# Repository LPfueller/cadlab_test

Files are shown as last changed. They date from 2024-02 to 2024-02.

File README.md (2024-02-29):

View this project on [CADLAB.io](https://cadlab.io/project/27833). 

# Crino Board - Template (RevB.1.0)

Crino offers precise characterisations of lithium ion cells for quality control in battery manufacturing and research using the *crino instrument*. Every crino instrument consists of several *crino boards* with actuators and sensors that are connected to a central control system (currently a *Raspberry Pi*). This control system is performing all measurements and also provides a user interface to interact with the system. This repository consists of Kicad development files for the *board-template*. All *crino boards* should be derived from this template. 

## Project directory structure

- **docs**: Contains additional documentation of the project.
- **hardware**: Contains the KiCad project.
- **hardware/fab**: Contains automatically generated BOM, and gerber files.
- **simulation**: Contains LTSpice simulations related to this project.

## Local Development Experience

**Prerequisites**:

If you are new to `crino development workflow`, please visit [crino-onboarding](https://github.com/crinolab/crino-onboarding) and [crino-onboarding-ecad](https://github.com/crinolab/crino-onboarding-ecad/tree/master/ecad) first.

**How to use the Template**:

Open Kicad, create a `new Project by Template`. Navigate to the following path and select the *Board Template*. Create a new project with the selected template.

- `<your path>crino-repos/crino-board/ecad/hardware`

In order to update the schematics, the newly created project has to be linked to the template. Use [git submodules](https://git-scm.com/book/en/v2/Git-Tools-Submodules) to link this repository to your task specific crino-board.

- `git submodule add -f https://github.com/crinolab/crino-board.git ./ecad/hardware/crino-board`

If you want to update you task specific crino-board to a new template, use 

- `git submodule update --init --recursive`

Open Kicad again and switch to the schematics of your new project. A block called `mcu` should be visible. Enter the properties dialog and change the *sheet name* to the following path.

- `.\crino-board\ecad\hardware\mcu.sch`

Now the schematics are linked to the template project. Appending all the symbols may be necessary. 

**How to apply changes in the Layout**

in order to apply changes in the Layout. The [KiCad Action Plugins](https://github.com/MitjaNemec/Kicad_action_plugins) have to be installed. Follow the instructions on the website.  

**Workflow for the Plugin (Rev1)**

1. After updating the submodule open the template folder
2. Open the template-layout and select TP14 (Reference Point)
3. `Tools -> External Plugins -> Save/Restore Layout -> Save Layout`
4. Select `mcu.sch` in the window and save `mcu.pckl`
5. Close template layout without saving
6. Open `mcu.pckl` and change Row `5720` 

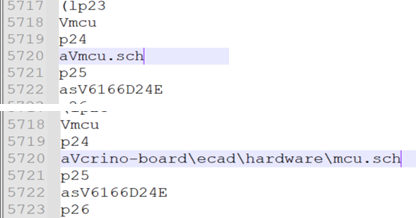
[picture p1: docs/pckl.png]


7. Open project and inspect the schematics
8. Open layout and note position of TP14
9. Delete all footprints and fracks of the template part
10. Start `Update PCB` and place the Footprints anywhere
11. Place TP14 at noted position and select it
12. `Tools -> External Plugins -> Save/Restore Layout -> Restore Layout`
13. Select `mcu.pckl` and wait until completed
14. Start DRC and correct errors
15. Save the Layout
16. Delete `mcu.pckl`

## General Components

The Template is the successor of the previously used [ESP32-POE-ISO](https://www.olimex.com/Products/IoT/ESP32/ESP32-POE-ISO/open-source-hardware). It contains all needed components of the board. 

**Basic Blocks**

The following blocks are present in the schematics:

- `poe` - Power over Ethernet controller
- `power` - Power supply for microcontroller (3.3V, 5V, 12V)
- `esp32` - [Microcontroller](https://www.espressif.com/sites/default/files/documentation/esp32-wroom-32e_esp32-wroom-32ue_datasheet_en.pdf) and programming interface  
- `ethernet` - Ethernet controller
- `io` - Pinout for derived boards

> Before you start making changes, please read the [development workflow](./docs/development-workflow.md) for Crino Power Board.

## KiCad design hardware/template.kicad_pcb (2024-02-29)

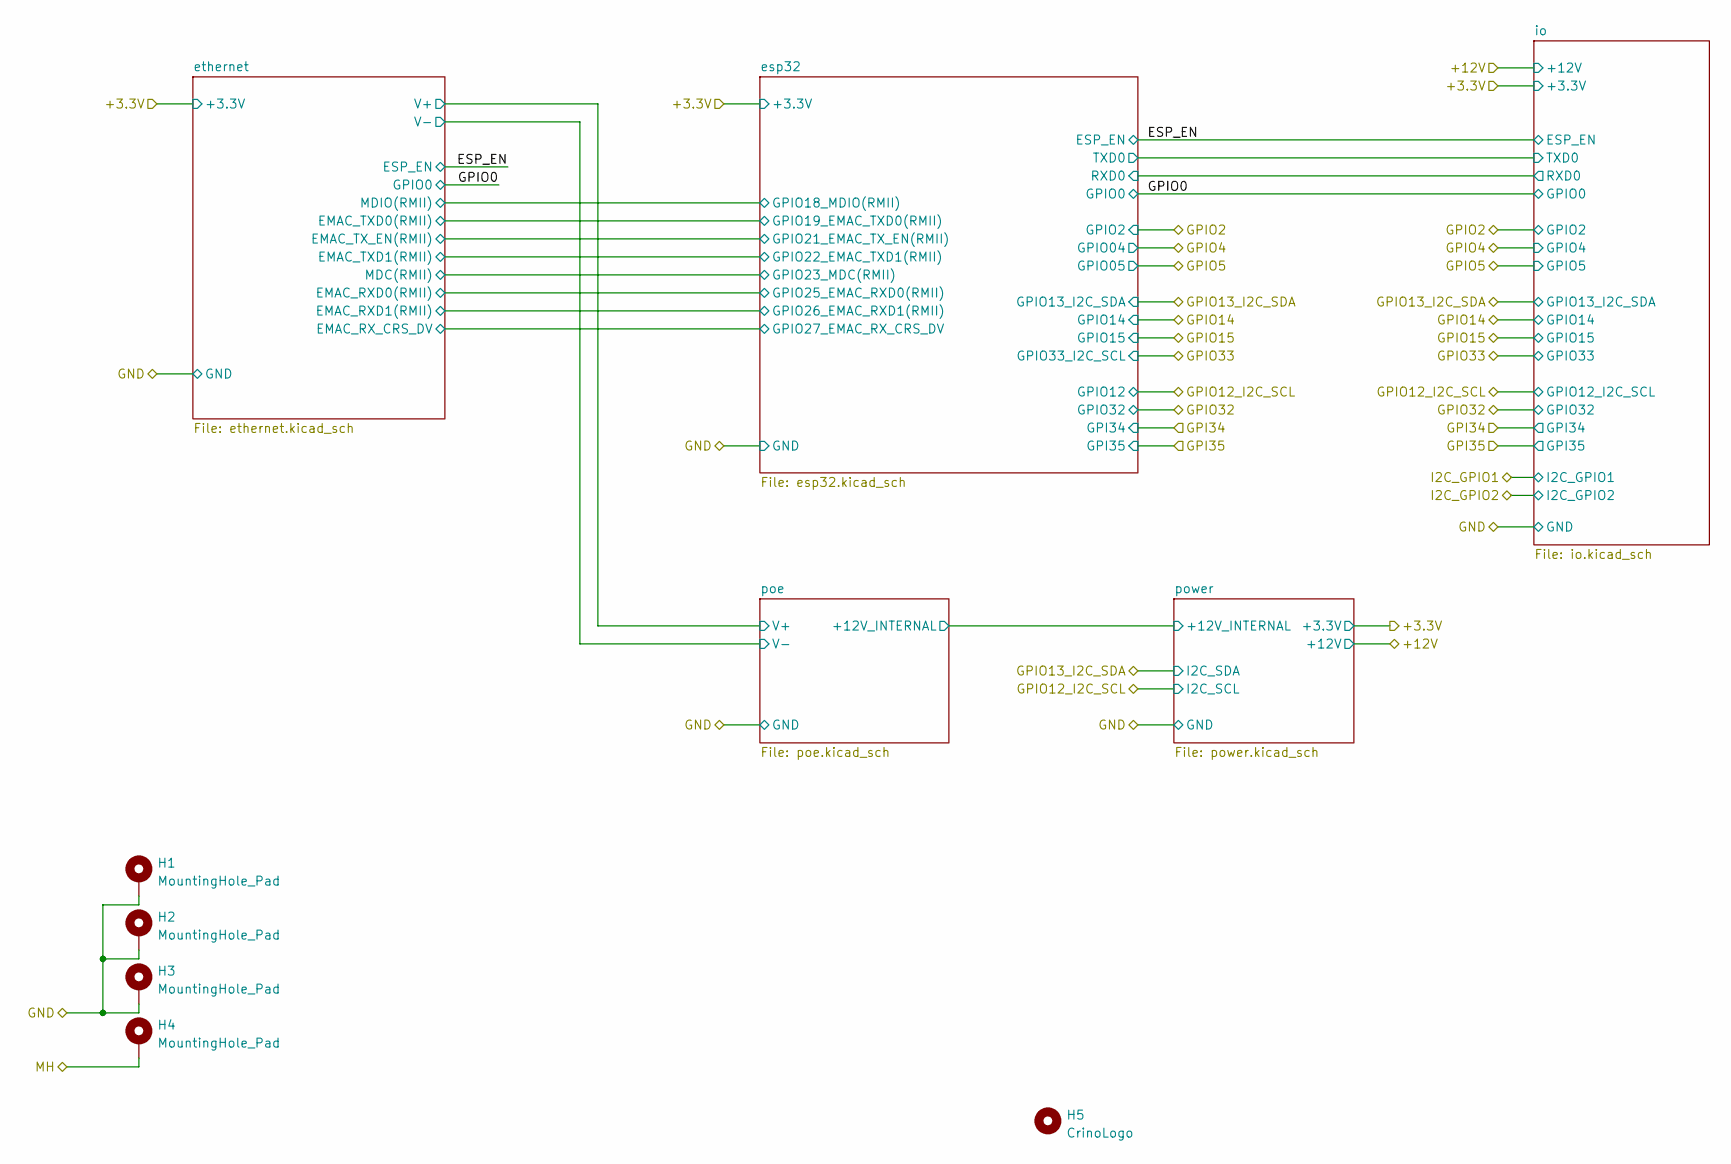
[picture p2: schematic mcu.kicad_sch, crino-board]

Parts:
H1, H2, H3, H4: MountingHole_Pad; MountingHole_3.2mm_M3_DIN965_Pad
H5: CrinoLogo; crino_logo

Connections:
/mcu/GND: H1.1, H2.1, H3.1; also elsewhere on the board
/mcu/MH: H4.1

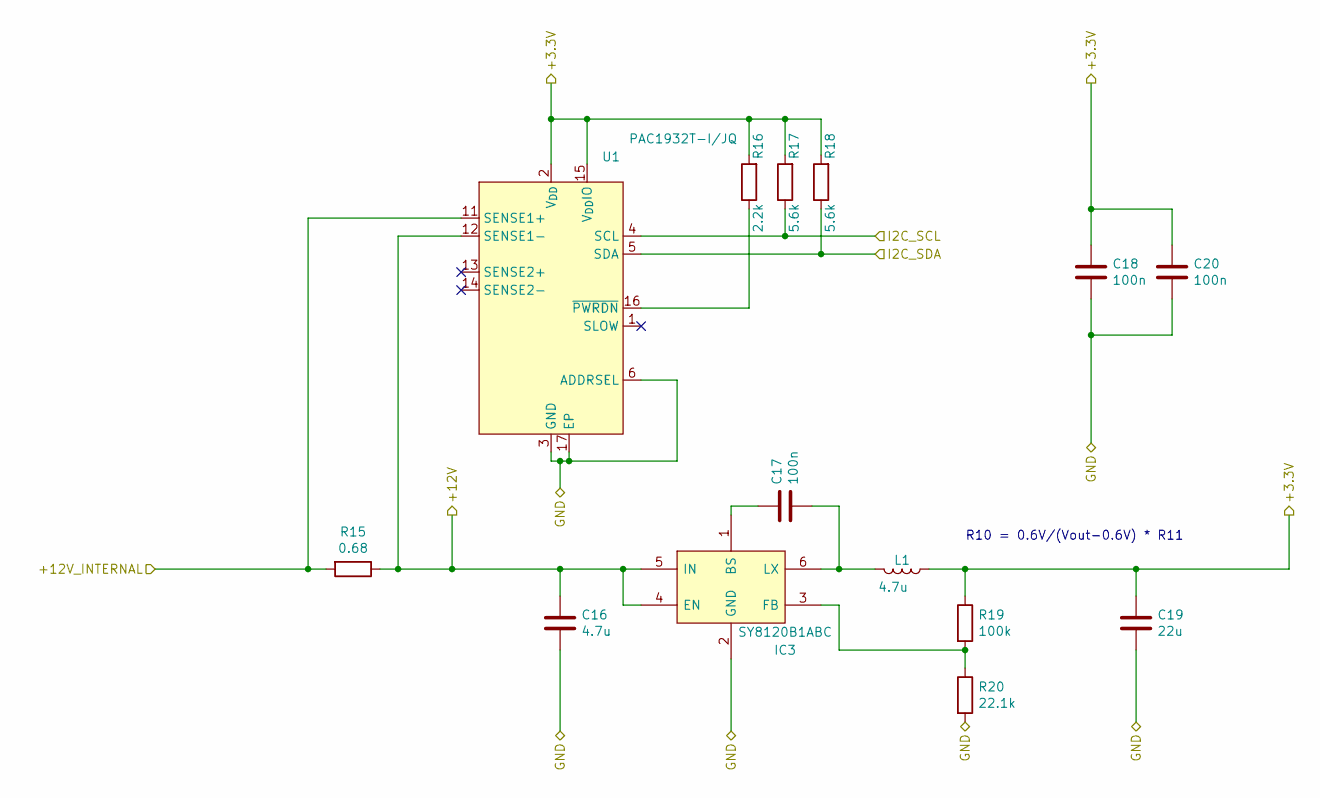
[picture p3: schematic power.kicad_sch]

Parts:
C16: 4.7u; C_0603_1608Metric; Manufacturer_Part_Number CL10A475KO8NNNC; jlc C19666
C17: 100n; C_0805_2012Metric; Manufacturer_Part_Number CL21B104KCFNNNE; jlc C28233
C18, C20: 100n; C_0603_1608Metric; Manufacturer_Part_Number CC0603KRX7R9BB104; jlc C14663
C19: 22u; C_1206_3216Metric; Manufacturer_Part_Number CL31A226KOHNNNE; jlc C90146
IC3: SY8120B1ABC; SOT-23-6; Manufacturer_Part_Number SY8120IABC; jlc C479076
L1: 4.7u; L_4.2x4.2_H2; Manufacturer_Part_Number SLW4020S4R7MST; jlc C206288
R15: 0.68; R_0805_2012Metric; Manufacturer_Part_Number SR732ATTDR680F; jlc C186593
R16: 2.2k; R_0603_1608Metric; Manufacturer_Part_Number 0603WAF2201T5E; jlc C4190
R17, R18: 5.6k; R_0603_1608Metric; Manufacturer_Part_Number 0603WAF5601T5E; jlc C23189
R19: 100k; R_0603_1608Metric; Manufacturer_Part_Number 0603WAF1003T5E; jlc C25803
R20: 22.1k; R_0603_1608Metric; Manufacturer_Part_Number 0603WAF2212T5E; jlc C25961
U1: PAC1932T-I/JQ; UQFN-16-1EP_4x4mm_P0.65mm_EP2.6x2.6mm; Manufacturer_Part_Number PAC1932T-I/JQ; jlc C623958

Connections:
/mcu/+3.3V: C18.1, C19.1, C20.1, L1.1, R16.2, R17.2, R18.2, R19.1, U1.2 (V_{DD}), U1.15 (V_{DD}IO); also elsewhere on the board
/mcu/+12V: C16.1, IC3.4 (EN), IC3.5 (IN), R15.1, U1.12 (SENSE1-); also elsewhere on the board
/mcu/GND: C16.2, C18.2, C19.2, C20.2, IC3.2 (GND), R20.2, U1.3 (GND), U1.6 (ADDRSEL), U1.7 (GND), U1.8 (GND), U1.9 (GND), U1.10 (GND), U1.17 (EP); also elsewhere on the board
/mcu/GPIO12_I2C_SCL: R17.1, U1.4 (SCL); also elsewhere on the board
/mcu/GPIO13_I2C_SDA: R18.1, U1.5 (SDA); also elsewhere on the board
/mcu/poe/+12V_INTERNAL: R15.2, U1.11 (SENSE1+); also elsewhere on the board
unnamed: C17.1, IC3.1 (BS)
unnamed: C17.2, IC3.6 (LX), L1.2
unnamed: IC3.3 (FB), R19.2, R20.1
unnamed: R16.1, U1.16 (~PWRDN)

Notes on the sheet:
R10 = 0.6V/(Vout-0.6V) * R11

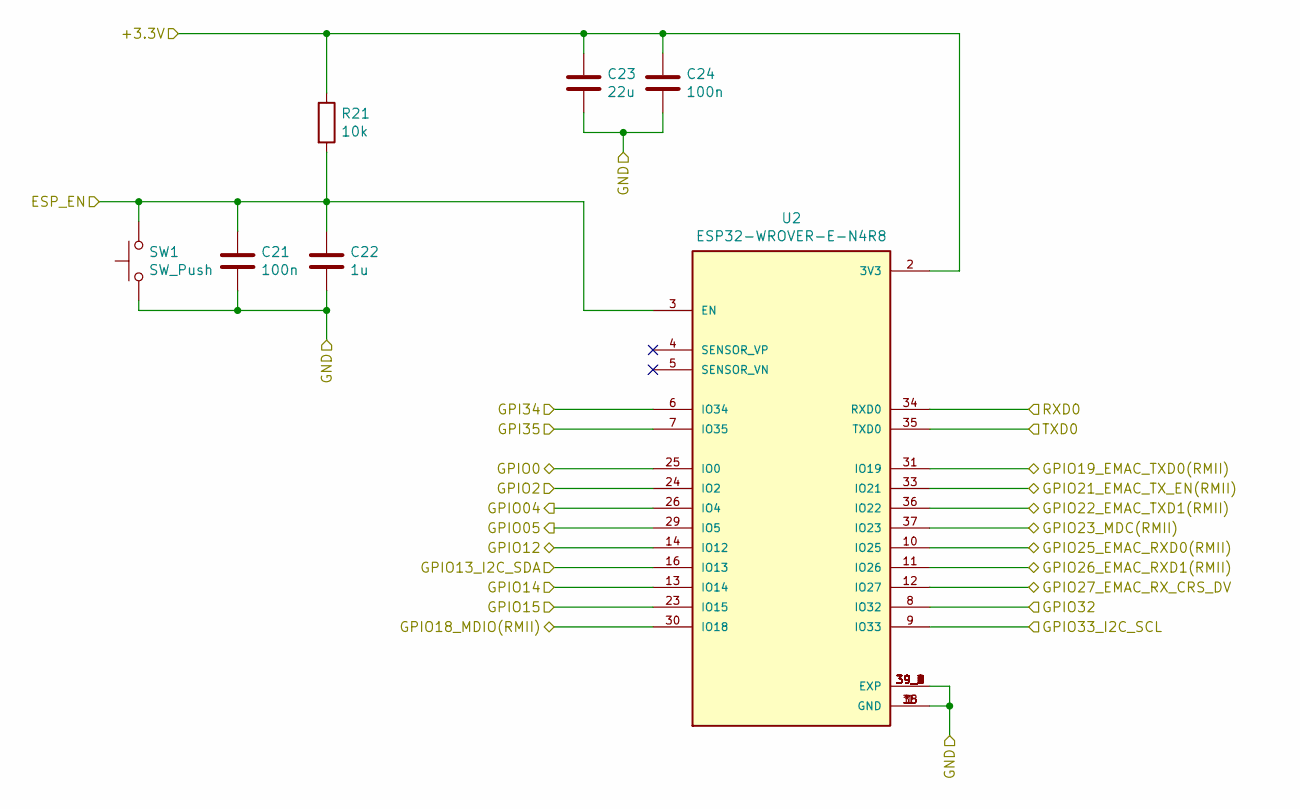
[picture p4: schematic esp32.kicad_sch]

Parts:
C21: 100n; C_0805_2012Metric; Manufacturer_Part_Number CL21B104KCFNNNE; jlc C28233
C22: 1u; C_0603_1608Metric; Manufacturer_Part_Number CL10A105KB8NNNC; jlc C15849
C23: 22u; C_0603_1608Metric; Manufacturer_Part_Number CL10A226MQ8NRNC; jlc C59461
C24: 100n; C_0603_1608Metric; Manufacturer_Part_Number CC0603KRX7R9BB104; jlc C14663
R21: 10k; R_0603_1608Metric; Manufacturer_Part_Number 0603WAF1002T5E; jlc C25804
SW1: SW_Push; SW_TS-1187A-B-A-B; Manufacturer_Part_Number TS-1187A-B-A-B; jlc C318884
U2: ESP32-WROVER-E-N4R8; PARTREV 1.6; jlc C967023

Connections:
/mcu/+3.3V: C23.1, C24.1, R21.1, U2.2 (3V3); also elsewhere on the board
/mcu/ESP_EN: C21.1, C22.1, R21.2, SW1.2, U2.3 (EN); also elsewhere on the board
/mcu/GND: C21.2, C22.2, C23.2, C24.2, SW1.1, U2.1 (GND), U2.15 (GND), U2.38 (GND), U2.39_1 (EXP), U2.39_2 (EXP), U2.39_3 (EXP), U2.39_4 (EXP), U2.39_5 (EXP), U2.39_6 (EXP), U2.39_7 (EXP), U2.39_8 (EXP), U2.39_9 (EXP); also elsewhere on the board
/mcu/GPI34: U2.6 (IO34); also elsewhere on the board
/mcu/GPI35: U2.7 (IO35); also elsewhere on the board
/mcu/GPIO0: U2.25 (IO0); also elsewhere on the board
/mcu/GPIO2: U2.24 (IO2); also elsewhere on the board
/mcu/GPIO4: U2.26 (IO4); also elsewhere on the board
/mcu/GPIO5: U2.29 (IO5); also elsewhere on the board
/mcu/GPIO12_I2C_SCL: U2.14 (IO12); also elsewhere on the board
/mcu/GPIO13_I2C_SDA: U2.16 (IO13); also elsewhere on the board
/mcu/GPIO14: U2.13 (IO14); also elsewhere on the board
/mcu/GPIO15: U2.23 (IO15); also elsewhere on the board
/mcu/GPIO32: U2.8 (IO32); also elsewhere on the board
/mcu/GPIO33: U2.9 (IO33); also elsewhere on the board
/mcu/esp32/GPIO18_MDIO(RMII): U2.30 (IO18); also elsewhere on the board
/mcu/esp32/GPIO19_EMAC_TXD0(RMII): U2.31 (IO19); also elsewhere on the board
/mcu/esp32/GPIO21_EMAC_TX_EN(RMII): U2.33 (IO21); also elsewhere on the board
/mcu/esp32/GPIO22_EMAC_TXD1(RMII): U2.36 (IO22); also elsewhere on the board
/mcu/esp32/GPIO23_MDC(RMII): U2.37 (IO23); also elsewhere on the board
/mcu/esp32/GPIO25_EMAC_RXD0(RMII): U2.10 (IO25); also elsewhere on the board
/mcu/esp32/GPIO26_EMAC_RXD1(RMII): U2.11 (IO26); also elsewhere on the board
/mcu/esp32/GPIO27_EMAC_RX_CRS_DV: U2.12 (IO27); also elsewhere on the board
/mcu/esp32/RXD0: U2.34 (RXD0); also elsewhere on the board
/mcu/esp32/TXD0: U2.35 (TXD0); also elsewhere on the board

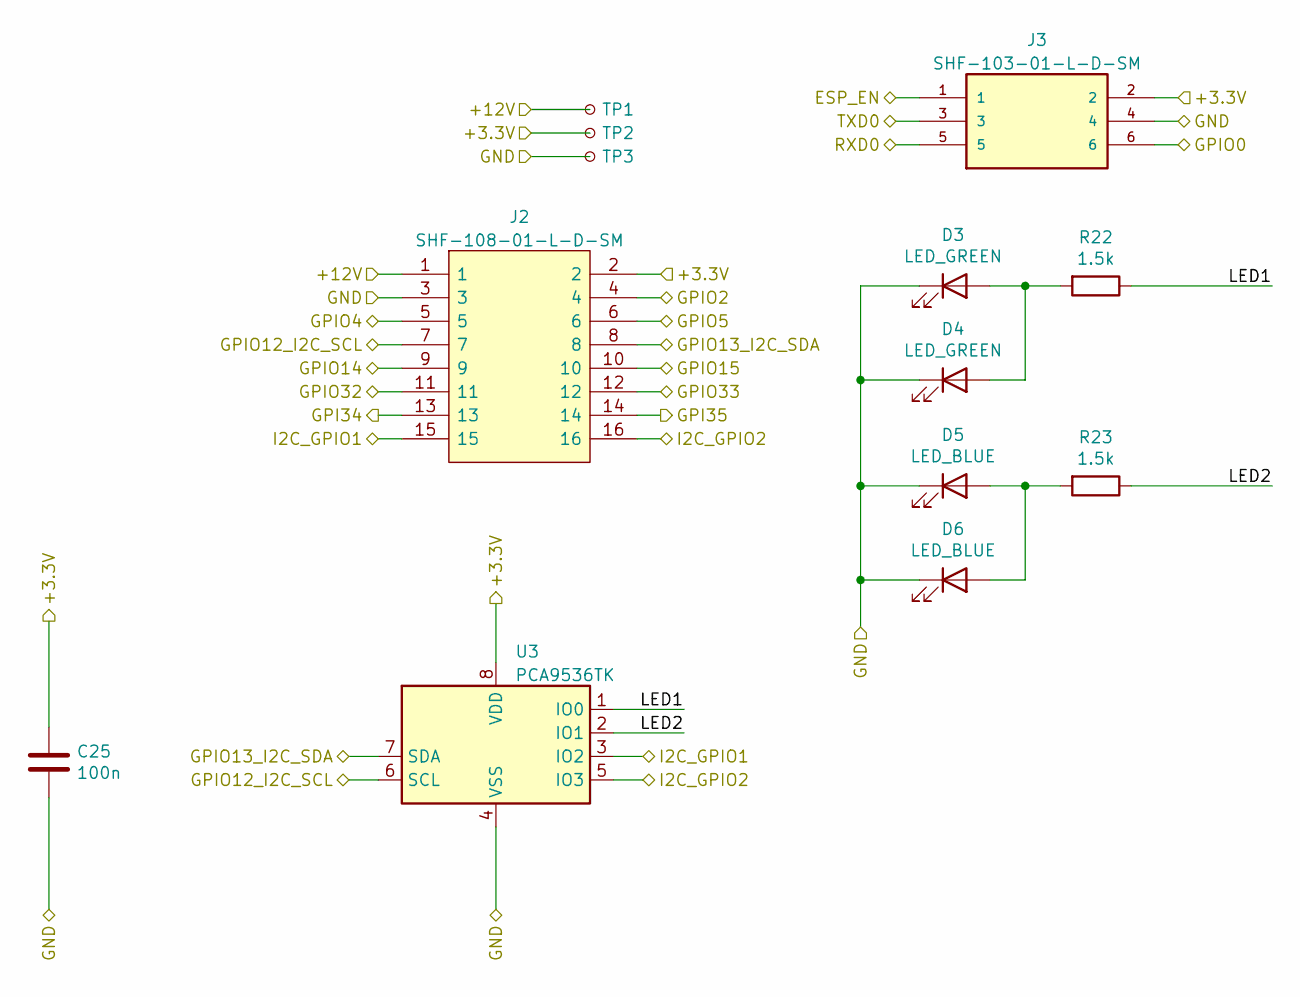
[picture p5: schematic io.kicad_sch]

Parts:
C25: 100n; C_0603_1608Metric; Manufacturer_Part_Number CC0603KRX7R9BB104; jlc C14663
D3, D4: LED_GREEN; LED_3210Metric_Right_Angle; Manufacturer_Part_Number TJ-S3210SW5TGLC2G-A5; jlc C273630
D5, D6: LED_BLUE; LED_3210Metric_Right_Angle; Manufacturer_Part_Number TJ-S3210SW5TGLC6B-A5; jlc C273631
J2: SHF-108-01-L-D-SM; SHF-108-01-X-D-SM; Manufacturer_Part_Number SHF-108-01-L-D-SM; Mouser Part Number 200-SHF10801LDSM
J3: SHF-103-01-L-D-SM; SAMTEC_SHF-103-01-L-D-SM; PARTREV R
R22, R23: 1.5k; R_0603_1608Metric; Manufacturer_Part_Number 0603WAF1501T5E; jlc C22843
TP1: 12V; TestPoint_Pad_D2.0mm
TP2: 3.3V; TestPoint_Pad_D2.0mm
TP3: GND; TestPoint_Pad_D2.0mm
U3: PCA9536TK; SON50P300X300X100-9N-D; Manufacturer_Part_Number PCA9536TK,118; jlc C2652283

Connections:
/mcu/+3.3V: C25.1, J2.2, J3.2, TP2.1, U3.8 (VDD); also elsewhere on the board
/mcu/+12V: J2.1, TP1.1; also elsewhere on the board
/mcu/ESP_EN: J3.1; also elsewhere on the board
/mcu/GND: C25.2, D3.1 (K), D4.1 (K), D5.1 (K), D6.1 (K), J2.3, J3.4, TP3.1, U3.4 (VSS); also elsewhere on the board
/mcu/GPI34: J2.13; also elsewhere on the board
/mcu/GPI35: J2.14; also elsewhere on the board
/mcu/GPIO0: J3.6; also elsewhere on the board
/mcu/GPIO2: J2.4; also elsewhere on the board
/mcu/GPIO4: J2.5; also elsewhere on the board
/mcu/GPIO5: J2.6; also elsewhere on the board
/mcu/GPIO12_I2C_SCL: J2.7, U3.6 (SCL); also elsewhere on the board
/mcu/GPIO13_I2C_SDA: J2.8, U3.7 (SDA); also elsewhere on the board
/mcu/GPIO14: J2.9; also elsewhere on the board
/mcu/GPIO15: J2.10; also elsewhere on the board
/mcu/GPIO32: J2.11; also elsewhere on the board
/mcu/GPIO33: J2.12; also elsewhere on the board
/mcu/I2C_GPIO1: J2.15, U3.3 (IO2)
/mcu/I2C_GPIO2: J2.16, U3.5 (IO3)
/mcu/esp32/RXD0: J3.5; also elsewhere on the board
/mcu/esp32/TXD0: J3.3; also elsewhere on the board
/mcu/io/LED1: R22.1, U3.1 (IO0)
/mcu/io/LED2: R23.1, U3.2 (IO1)
unnamed: D3.2 (A), D4.2 (A), R22.2
unnamed: D5.2 (A), D6.2 (A), R23.2

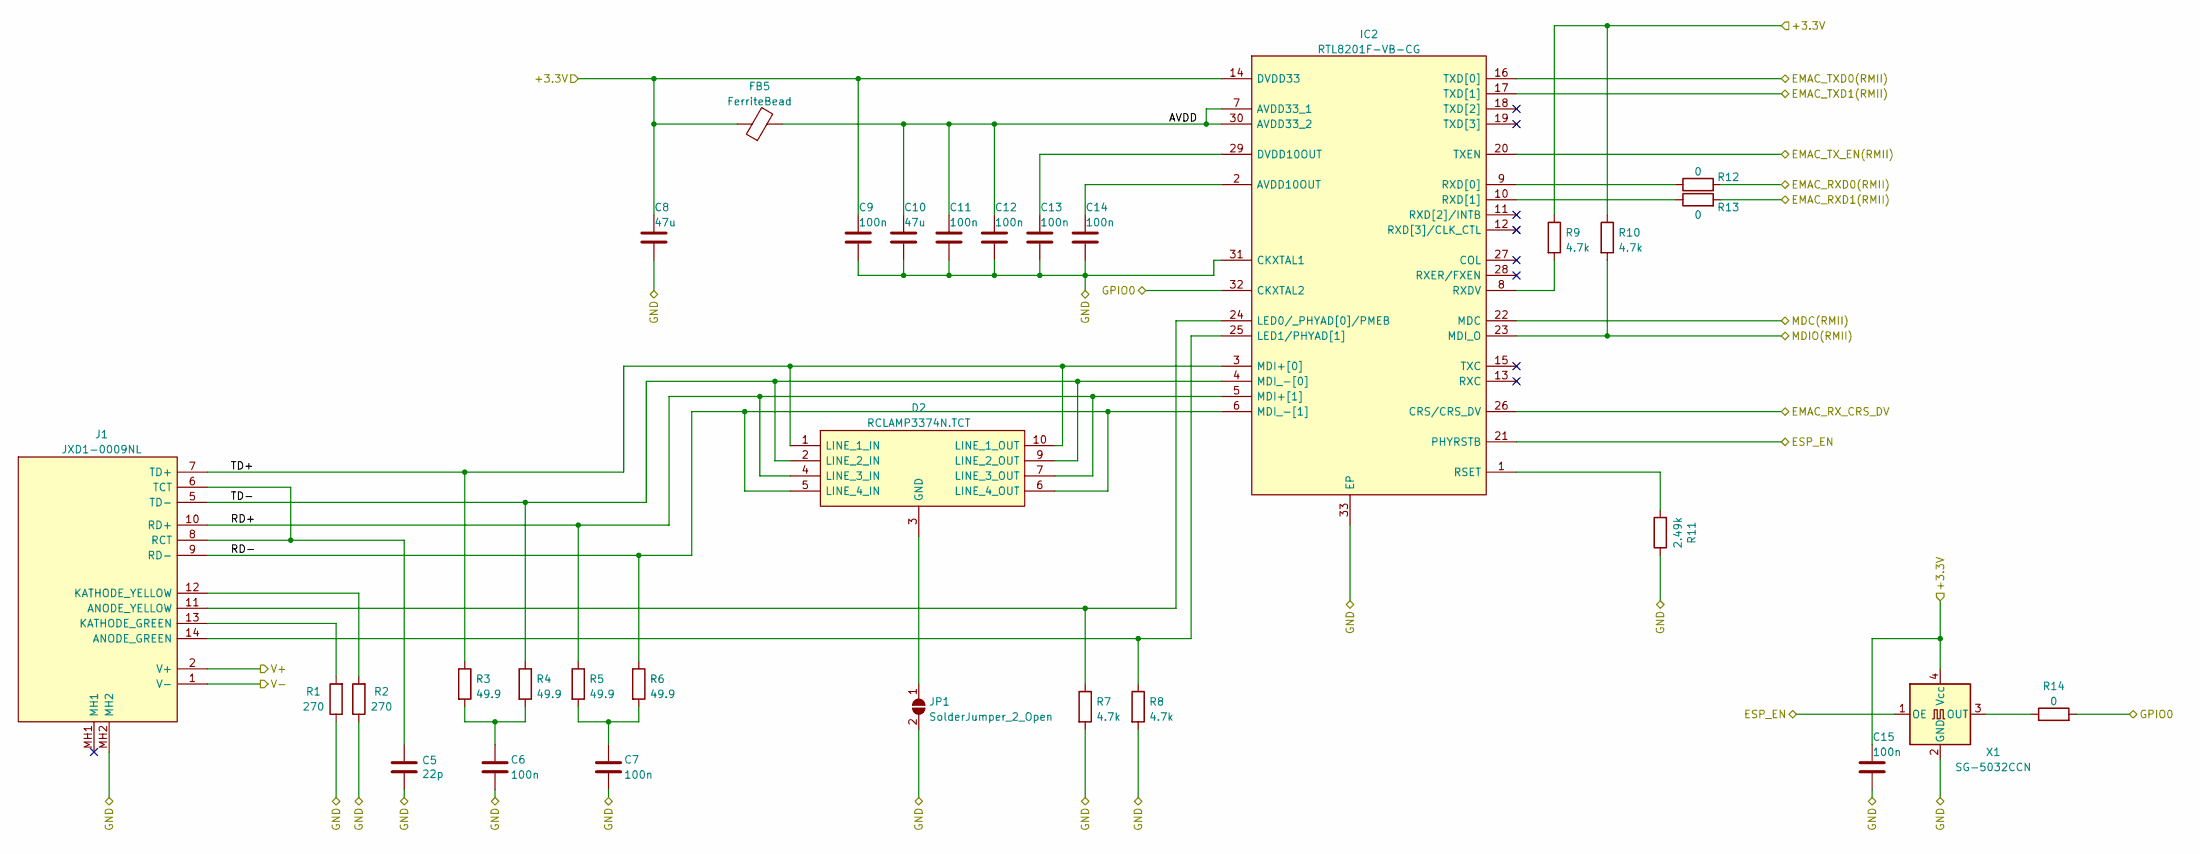
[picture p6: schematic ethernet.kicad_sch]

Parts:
C5: 22p; C_0603_1608Metric; Manufacturer_Part_Number CL10C220JB8NNNC; jlc C1653
C6, C7, C9, C11, C12, C13, C14, C15: 100n; C_0603_1608Metric; Manufacturer_Part_Number CC0603KRX7R9BB104; jlc C14663
C8, C10: 47u; C_0603_1608Metric; Manufacturer_Part_Number CL10A476MQ8QRNC; jlc C730416
D2: RCLAMP3374N.TCT; RCLAMP3374NTCT; Manufacturer_Part_Number TPRCLAMP3374N; Mouser Part Number 947-RCLAMP3374N.TCT
FB5: FerriteBead; L_0805_2012Metric; Manufacturer_Part_Number UPZ2012E601-2R0TF; jlc C98308
IC2: RTL8201F-VB-CG; QFN-32-1EP_5x5mm_P0.5mm_EP3.6x3.6mm_ThermalVias; Manufacturer_Part_Number RTL8201F-VB-CG; jlc C45044
J1: JXD1-0009NL; JXD10009NL; Manufacturer_Part_Number JXD1-0009NL; Mouser Part Number 673-JXD1-0009NL
JP1: SolderJumper_2_Open; SolderJumper-2_P1.3mm_Open_RoundedPad1.0x1.5mm
R1, R2: 270; R_0603_1608Metric; Manufacturer_Part_Number 0603WAF2700T5E; jlc C22966
R3, R4, R5, R6: 49.9; R_0603_1608Metric; Manufacturer_Part_Number 0603WAF499JT5E; jlc C23185
R7, R8, R9, R10: 4.7k; R_0603_1608Metric; Manufacturer_Part_Number 0603WAF4701T5E; jlc C23162
R11: 2.49k; R_0603_1608Metric; Manufacturer_Part_Number 0603WAF2491T5E; jlc C22908
R12, R13, R14: 0; R_0603_1608Metric; Manufacturer_Part_Number 0603WAF0000T5E; jlc C21189
X1: SG-5032CCN; Oscillator_SMD_SeikoEpson_SG8002LB-4Pin_5.0x3.2mm; Manufacturer_Part_Number S5D50.000000B20F30T; jlc C387308

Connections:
/mcu/+3.3V: C8.1, C9.1, C15.1, FB5.1, IC2.14 (DVDD33), R9.1, R10.1, X1.4 (Vcc); also elsewhere on the board
/mcu/ESP_EN: IC2.21 (PHYRSTB), X1.1 (OE); also elsewhere on the board
/mcu/GND: C5.2, C6.2, C7.2, C8.2, C9.2, C10.2, C11.2, C12.2, C13.2, C14.2, C15.2, IC2.31 (CKXTAL1), IC2.33 (EP), J1.MH2, JP1.2 (B), R1.1, R2.1, R7.2, R8.2, R11.1, X1.2 (GND); also elsewhere on the board
/mcu/GPIO0: IC2.32 (CKXTAL2), R14.2; also elsewhere on the board
/mcu/esp32/GPIO18_MDIO(RMII): IC2.23 (MDI_O), R10.2; also elsewhere on the board
/mcu/esp32/GPIO19_EMAC_TXD0(RMII): IC2.16 (TXD[0]); also elsewhere on the board
/mcu/esp32/GPIO21_EMAC_TX_EN(RMII): IC2.20 (TXEN); also elsewhere on the board
/mcu/esp32/GPIO22_EMAC_TXD1(RMII): IC2.17 (TXD[1]); also elsewhere on the board
/mcu/esp32/GPIO23_MDC(RMII): IC2.22 (MDC); also elsewhere on the board
/mcu/esp32/GPIO25_EMAC_RXD0(RMII): R12.2; also elsewhere on the board
/mcu/esp32/GPIO26_EMAC_RXD1(RMII): R13.2; also elsewhere on the board
/mcu/esp32/GPIO27_EMAC_RX_CRS_DV: IC2.26 (CRS/CRS_DV); also elsewhere on the board
/mcu/ethernet/AVDD: C10.1, C11.1, C12.1, FB5.2, IC2.7 (AVDD33_1), IC2.30 (AVDD33_2)
/mcu/ethernet/RD+: D2.4 (LINE_3_IN), D2.7 (LINE_3_OUT), IC2.5 (MDI+[1]), J1.10 (RD+), R5.1
/mcu/ethernet/RD-: D2.5 (LINE_4_IN), D2.6 (LINE_4_OUT), IC2.6 (MDI_-[1]), J1.9 (RD-), R6.1
/mcu/ethernet/TD+: D2.1 (LINE_1_IN), D2.10 (LINE_1_OUT), IC2.3 (MDI+[0]), J1.7 (TD+), R3.1
/mcu/ethernet/TD-: D2.2 (LINE_2_IN), D2.9 (LINE_2_OUT), IC2.4 (MDI_-[0]), J1.5 (TD-), R4.1
/mcu/ethernet/V+: J1.2 (V+); also elsewhere on the board
/mcu/ethernet/V-: J1.1 (V-); also elsewhere on the board
unnamed: C5.1, J1.6 (TCT), J1.8 (RCT)
unnamed: C6.1, R3.2, R4.2
unnamed: C7.1, R5.2, R6.2
unnamed: C13.1, IC2.29 (DVDD10OUT)
unnamed: C14.1, IC2.2 (AVDD10OUT)
unnamed: D2.3 (GND), D2.8 (GND), D2.12 (GND), JP1.1 (A)
unnamed: IC2.1 (RSET), R11.2
unnamed: IC2.8 (RXDV), R9.2
unnamed: IC2.9 (RXD[0]), R12.1
unnamed: IC2.10 (RXD[1]), R13.1
unnamed: IC2.24 (LED0/_PHYAD[0]/PMEB), J1.11 (ANODE_YELLOW), R7.1
unnamed: IC2.25 (LED1/PHYAD[1]), J1.14 (ANODE_GREEN), R8.1
unnamed: J1.12 (KATHODE_YELLOW), R2.2
unnamed: J1.13 (KATHODE_GREEN), R1.2
unnamed: R14.1, X1.3 (OUT)

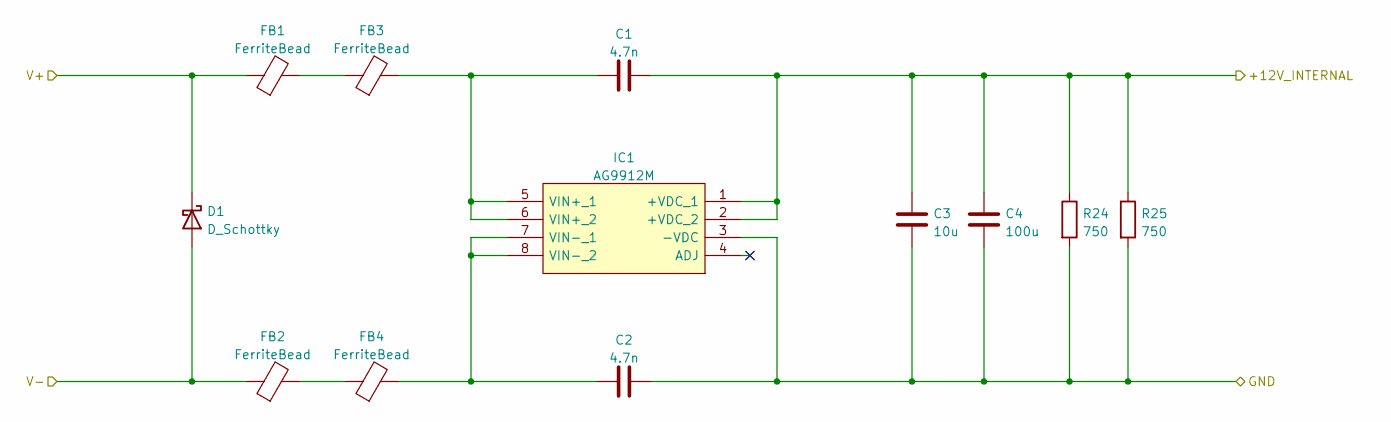
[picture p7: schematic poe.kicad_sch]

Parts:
C1, C2: 4.7n; C_1206_3216Metric; Manufacturer_Part_Number 1206B472K202NT; jlc C41017
C3: 10u; C_0805_2012Metric; Manufacturer_Part_Number GRM21BR61E106KA73L; jlc C84416
C4: 100u; CP_Elec_5x5.4; Manufacturer_Part_Number RVT1E100M0505; jlc C86604
D1: D_Schottky; D_SMA; Manufacturer_Part_Number SMAJ58A-TP; jlc C669036
FB1, FB2, FB3, FB4: FerriteBead; L_1206_3216Metric; Manufacturer_Part_Number BLM31KN102SN1L; jlc C560056
IC1: AG9912M; Mouser Part Number 480-AG9912M
R24, R25: 750; R_0805_2012Metric; Manufacturer_Part_Number ERJP06F7500V; jlc C441980

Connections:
/mcu/GND: C2.2, C3.2, C4.2, IC1.3 (-VDC), R24.2, R25.2; also elsewhere on the board
/mcu/ethernet/V+: D1.1 (K), FB1.1; also elsewhere on the board
/mcu/ethernet/V-: D1.2 (A), FB2.1; also elsewhere on the board
/mcu/poe/+12V_INTERNAL: C1.2, C3.1, C4.1, IC1.1 (+VDC_1), IC1.2 (+VDC_2), R24.1, R25.1; also elsewhere on the board
unnamed: C1.1, FB3.2, IC1.5 (VIN+_1), IC1.6 (VIN+_2)
unnamed: C2.1, FB4.2, IC1.7 (VIN-_1), IC1.8 (VIN-_2)
unnamed: FB1.2, FB3.1
unnamed: FB2.2, FB4.1

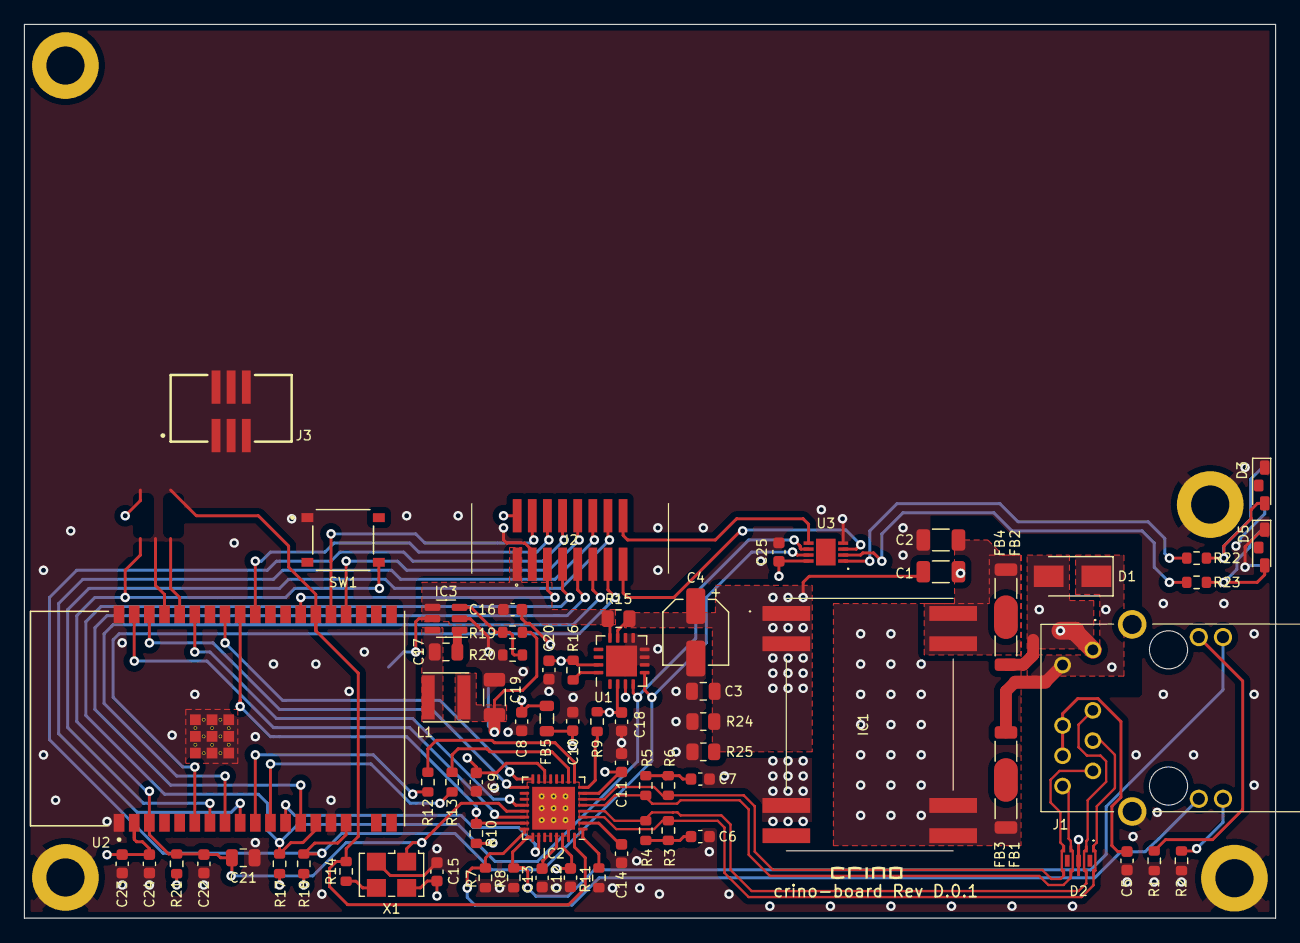
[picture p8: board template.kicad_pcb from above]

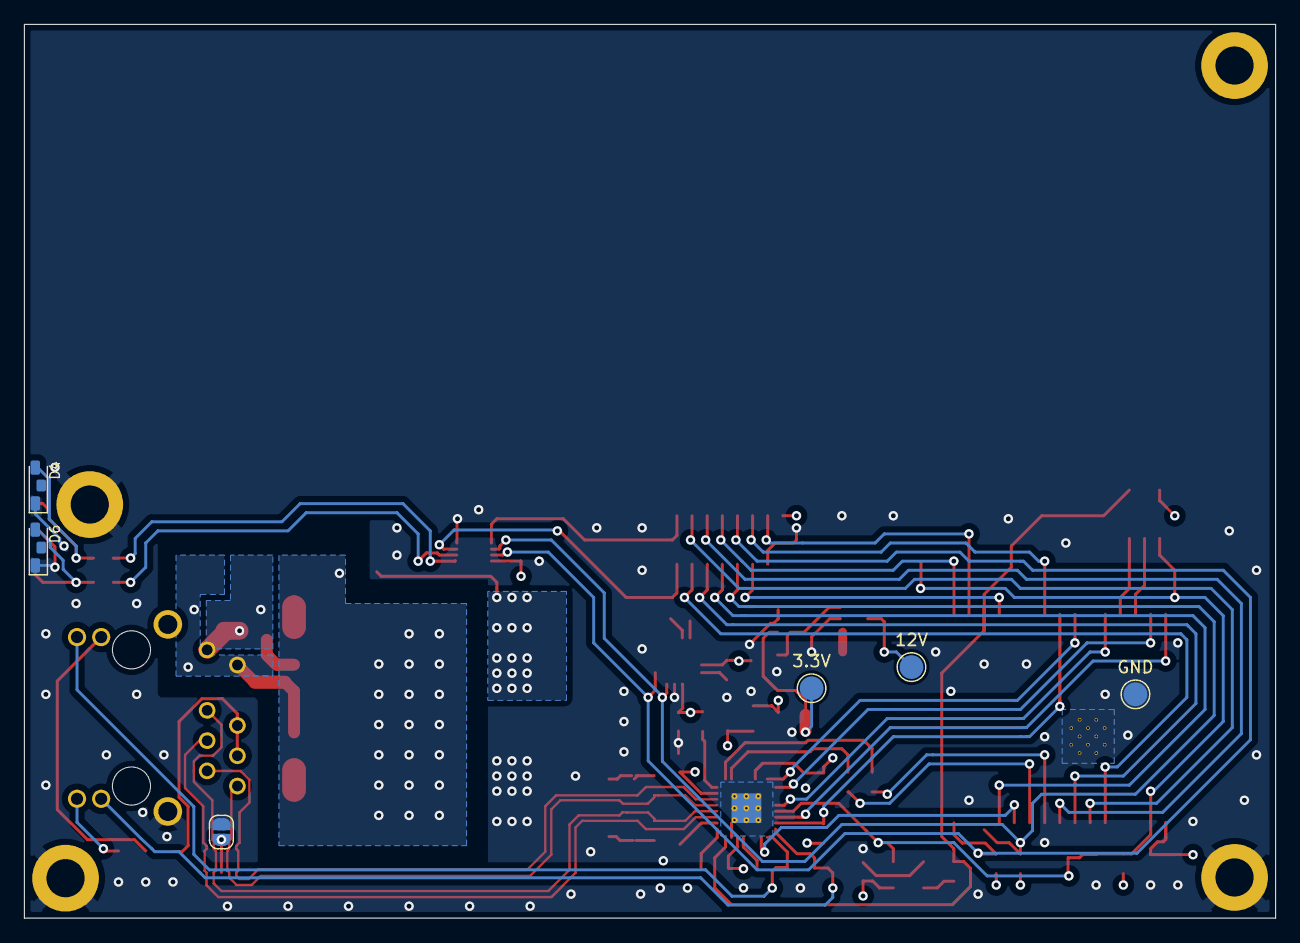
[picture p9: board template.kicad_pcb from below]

Board: 4 copper layers, 105.0 x 75.0 mm, 82 parts (6 on the bottom side), 63 nets.
